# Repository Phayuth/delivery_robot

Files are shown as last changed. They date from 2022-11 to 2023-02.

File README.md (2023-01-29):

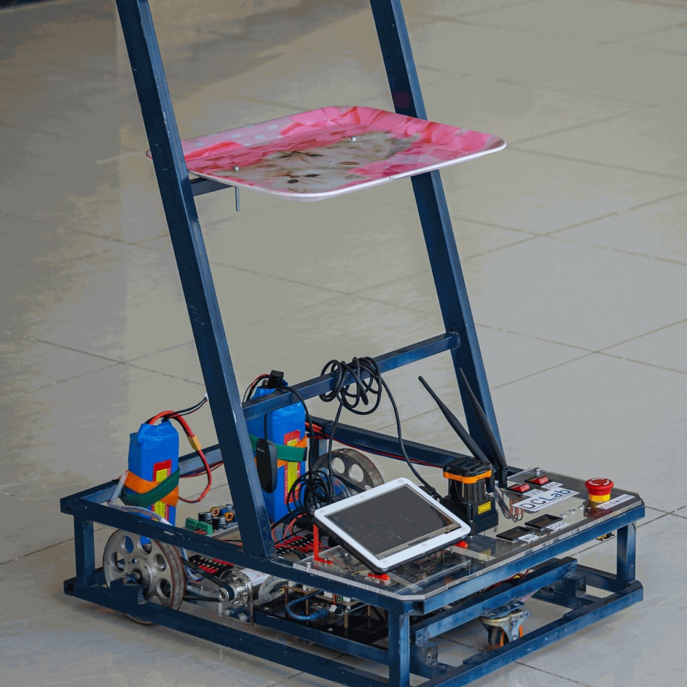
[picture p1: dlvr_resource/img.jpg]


# Delivery Mobile Robot
This Package is created for My Differential Drive Mobile Robot for Indoor Delivery. It is for ROS Melodic.[For Mom!]

### Reference [List](REFERENCES.md)
Some of the code is taken from some of other repo (all right belong to their respective author). There are detail of the package, read more in the references list link above.

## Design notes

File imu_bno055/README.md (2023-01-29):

# ROS driver for IMU Bosch BNO055 (I2C)
This is a ROS node for the BNO055 IMU that communicates via I2C and without any dependencies besides libi2c-dev. It does **not** require RTIMULib, RTIMULib2, RTIMULib3 or whatever the latest sequel is. It is specifically targeted at using a BNO055 with NVIDIA boards such as the TX1, TX2, and Xavier, or any other board that has native I2C.

The BNO055 supports I2C and UART communication. This driver supports I2C only. If you are looking for a UART driver, see [this driver](https://github.com/mdrwiega/bosch_imu_driver) by [mdrwiega](https://github.com/mdrwiega) instead.

## Parameters:

* **device** -- the path to the i2c device. Default is /dev/i2c-1. Use i2cdetect in the i2c-tools package to find out which bus your IMU is on.
* **address** -- the i2c address of the IMU. Default is 0x28.

## Outputs topics:
* **/data** (sensor\_msgs/Imu) -- fused IMU data
* **/raw** (sensor\_msgs/Imu) -- raw accelerometer data
* **/mag** (sensor\_msgs/MagneticField) -- raw magnetic field data
* **/temp** (sensor\_msgs/Temperature) -- temperature data
* **/status** (diagnostic\_msgs/DiagnosticStatus) -- a DiagnosticStatus object showing the current calibration, interrupt, system status of the IMU

## Service calls:
* **/reset** (std\_srvs/Trigger) -- resets the IMU
* **/calibrate** (std\_srvs/Trigger) -- not yet implemented

# Usage notes

## Raspberry Pi

The Raspberry Pi hardware I2C does not support clock stretching. You have two options:

* [Use software I2C](https://github.com/fivdi/i2c-bus/blob/master/doc/raspberry-pi-software-i2c.md) instead which supports clock stretching but will increase CPU usage slightly.
* [Slow down the I2C clock drastically](https://learn.adafruit.com/circuitpython-on-raspberrypi-linux/i2c-clock-stretching), since the Pi does not support clock stretching. I have not tested this method.

## NVIDIA Jetson platforms

You may need to add your user to the i2c group, e.g. `sudo usermod -aG i2c nvidia`. It should just work after that.

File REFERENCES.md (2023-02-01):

### Hardware
- 1 X Jetson Nano
- 1 X Arduino Due
- 1 X Custom Motor DiverIBT-2
- 1 X Custom Logic Level Converter
- 1 X IMU BNO055
- 2 X Gear DC Motor
- 1 X Lidar
- 1 X Camera
- 2 X Lipo Battery

### Install Prerequired Package
```
sudo apt-get install libgeographic-dev ros-melodic-libgeographic-info ros-melodic-libgeographic-dev
sudo apt-get install ros-melodic-openslam-gmapping ros-melodic-tf2-sensor-msgs
sudo apt-get install ros-melodic-laser-proc ros-melodic-urg-c
sudo apt-get install qt4-qmake qt4-dev-tools
sudo apt-get install ros-melodic-teleop-twist-keyboard
```
### Install Delivery Robot Package
-- To Do --

### Mobile Robot Parameter

| Params | Value |
|---|---|
| Width | ...m |
| Length | ...m |
| Height | ...m |
| Weight | ...kg |
| Base Length | 0.44 m |
| Wheel Radius | 0.07 m |
| Base to Caster Wheel | ...m |
| Ground Clearance | ...m |
| Motor Left a | 26.63 |
| Motor Left b | 17.26 |
| Motor Left c | 6.776 |
| Motor Left GR | 19.2x3.75 |
| Motor Left PPR | 28 |
| Motor Right a | 28.37 |
| Motor Right b | 19.15 |
| Motor Right c | 5.75 |
| Motor Right GR | 19.2x3.75 |
| Motor Right PPR | 28 |

### Support Repo
- [Hokuyo Lidar Package urg_node](https://github.com/ros-drivers/urg_node)
- [BNO055 Package](https://github.com/dheera/ros-imu-bno055)
- [Robot localization](https://github.com/cra-ros-pkg/robot_localization)
- [Gmapping](https://github.com/ros-perception/slam_gmapping)
- [Hector Slam](https://github.com/tu-darmstadt-ros-pkg/hector_slam)
- [ROS Navigation](http://wiki.ros.org/navigation)
- [ROS Serial](http://wiki.ros.org/rosserial)

### Other Repo
- [Grid Mapping](https://github.com/salihmarangoz/robot_laser_grid_mapping) - do a minimal laser grid mapping in python and ros
- [Laser Simulation from Image File](https://github.com/salihmarangoz/robot_laser_simulator) - create a simulation of laser scan from image file
- [Python for Robotic by AtsushiSakai](https://github.com/AtsushiSakai/PythonRobotics)

### Resoures and Issue
- [How to setup ros nav stack by automaticaddision](https://automaticaddison.com/how-to-set-up-the-ros-navigation-stack-on-a-robot/)
- [Arduino Due Board Installed on IDE](https://forum.arduino.cc/t/installing-arduino-sam-boards-on-arduino-ide-for-arm64/550398) - fix issue when installing arduino due board on nvidia jetson device
- [Why Odom frame and Map frame move away from each other](https://answers.ros.org/question/10302/the-tf-between-map-and-odom-is-not-static/#15185)
- [Install Hector SLAM](https://automaticaddison.com/how-to-build-an-indoor-map-using-ros-and-lidar-based-slam/)
- [Max range map](https://answers.ros.org/question/138591/gmapping-in-gazebo-with-hokuyo-problems-due-to-max-range-measurements/)
- [Pioneer 3pdx](https://www.generationrobots.com/media/Pioneer3DX-P3DX-RevA.pdf)

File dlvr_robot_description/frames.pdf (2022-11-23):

view_frames Result

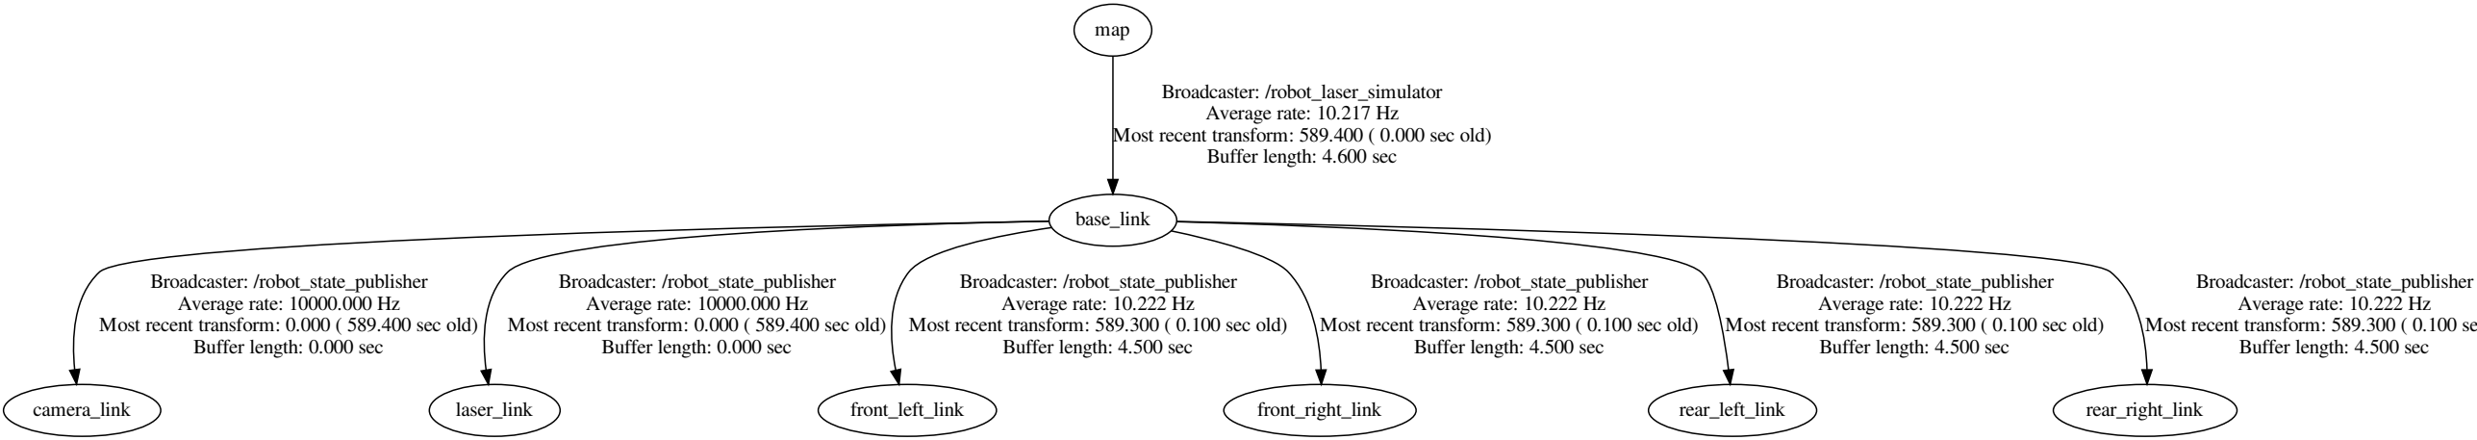
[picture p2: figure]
base_link; camera_link; Broadcaster: /robot_state_publisher Average rate: 10000.000 Hz; Buffer length: 0.000 sec; laser_link; front_left_link; Broadcaster: /robot_state_publisher Average rate: 10.222 Hz; Buffer length: 4.500 sec; front_right_link; rear_left_link; rear_right_link; map; Broadcaster: /robot_laser_simulator Average rate: 10.217 Hz; Buffer length: 4.600 sec

Most recent transform: 0.000 ( 589.400 sec old)

Most recent transform: 0.000 ( 589.400 sec old)

Most recent transform: 589.300 ( 0.100 sec old)

Most recent transform: 589.300 ( 0.100 sec old)

Most recent transform: 589.300 ( 0.100 sec old)

Most recent transform: 589.300 ( 0.100 sec old)

Most recent transform: 589.400 ( 0.000 sec old)

Recorded at time: 589.400

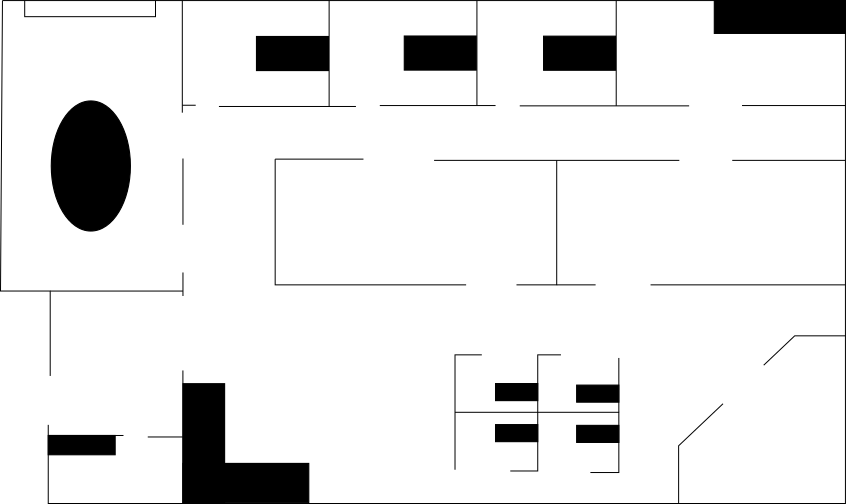
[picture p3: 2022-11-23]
dlvr_robot_laser_sim/launch/map1.png

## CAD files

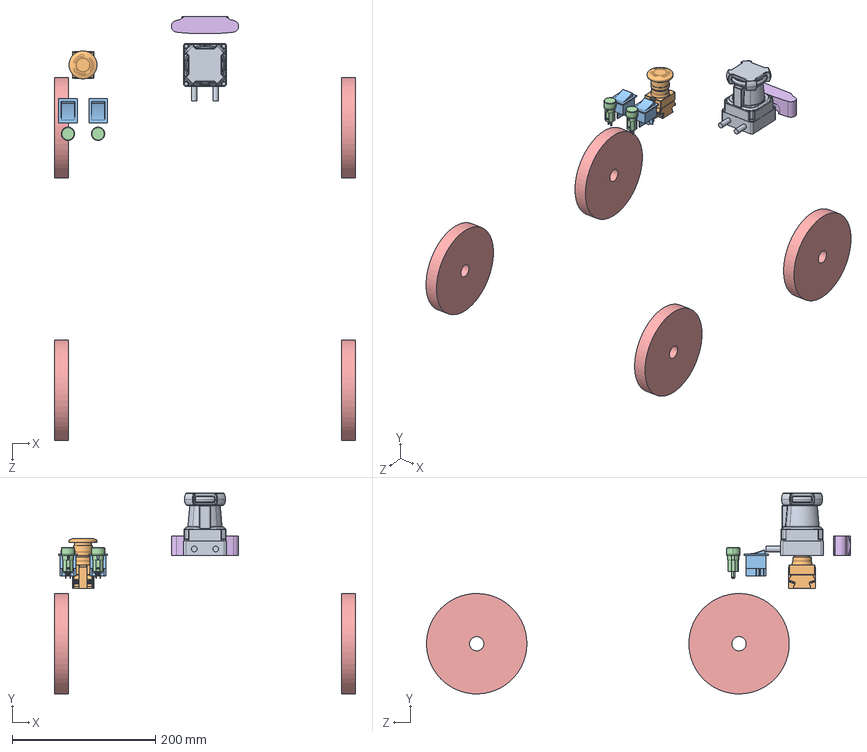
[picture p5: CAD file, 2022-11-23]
dlvr_resource/design/URDF_Export.SLDASM
420.0 x 280.0 x 591.0 mm
LIDAR_Hokuyo_UTM_30LX
E_Stop_Button
Battery_Switch x 2
LED_Indicator x 2
Wheel x 4
Logitech_C920

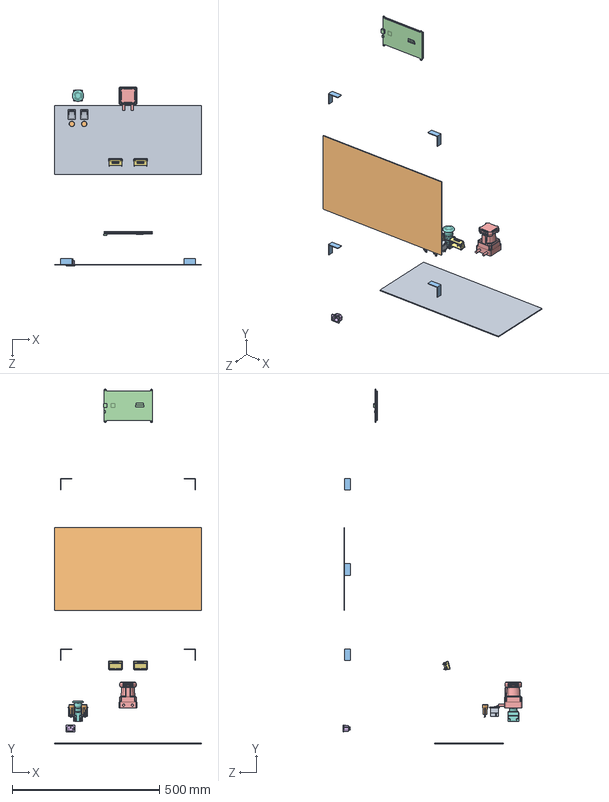
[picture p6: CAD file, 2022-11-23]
dlvr_resource/design/Assembly.SLDASM
500.0 x 1207.3 x 609.5 mm
Top_Back_Cover_2
Bottom_Battery_Support_1
Plate_Support x 6
LCD_Adafruit_HDMI_7inch
LIDAR_Hokuyo_UTM_30LX
AC_Power_Socket
Voltage_Display x 2
E_Stop_Button
Battery_Switch x 2
LED_Indicator x 2

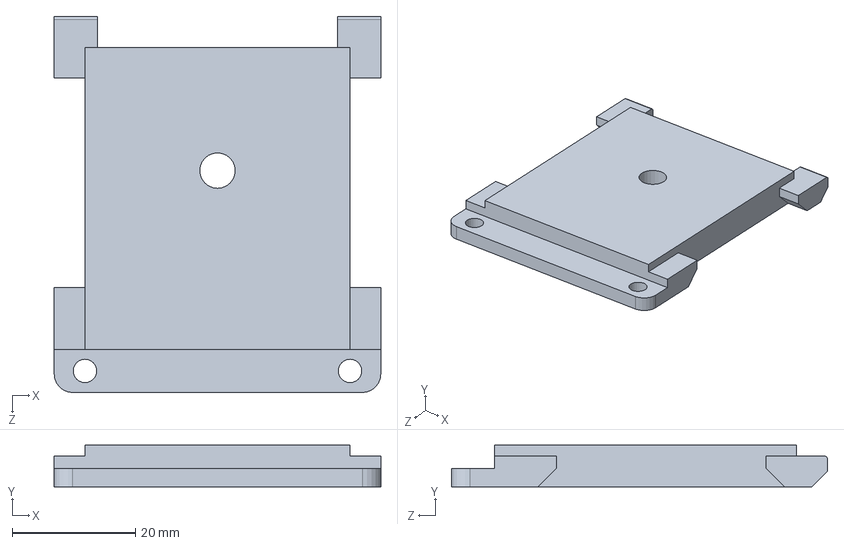
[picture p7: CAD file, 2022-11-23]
dlvr_resource/design/addon/delivery_camera_sup_b.SLDPRT
53.0 x 6.75 x 61.0 mm

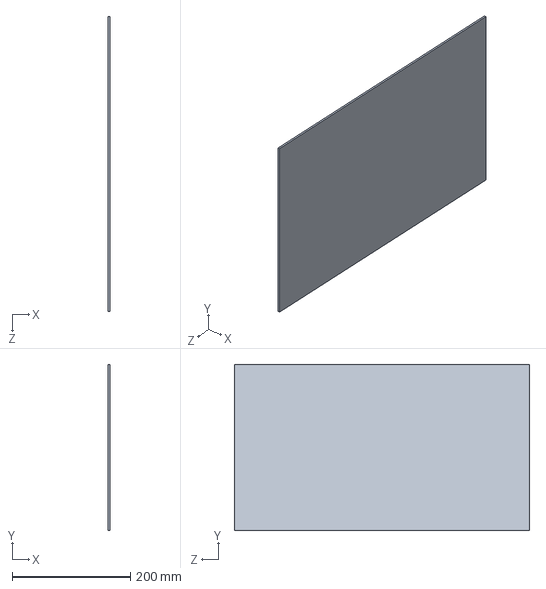
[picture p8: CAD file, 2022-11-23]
dlvr_resource/design/Part/Top_Back_Cover_2.SLDPRT
3.00 x 281.9 x 500.0 mm

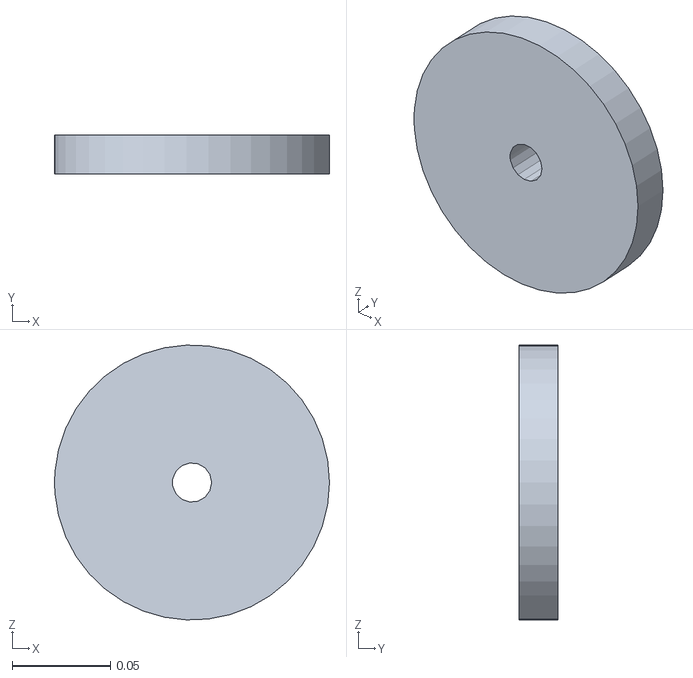
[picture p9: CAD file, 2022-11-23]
dlvr_robot_description/meshes/rear_left_link.STL
0.14 x 0.02 x 0.14

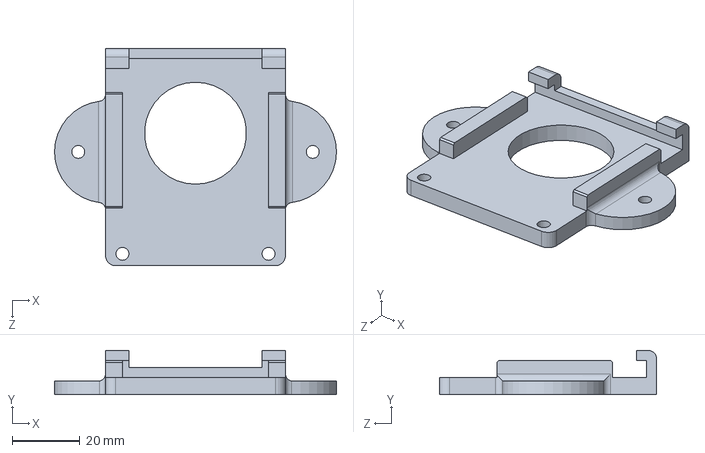
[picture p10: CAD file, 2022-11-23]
dlvr_resource/design/addon/delivery_camera_sup_a.SLDPRT
83.0 x 13.0 x 64.0 mm

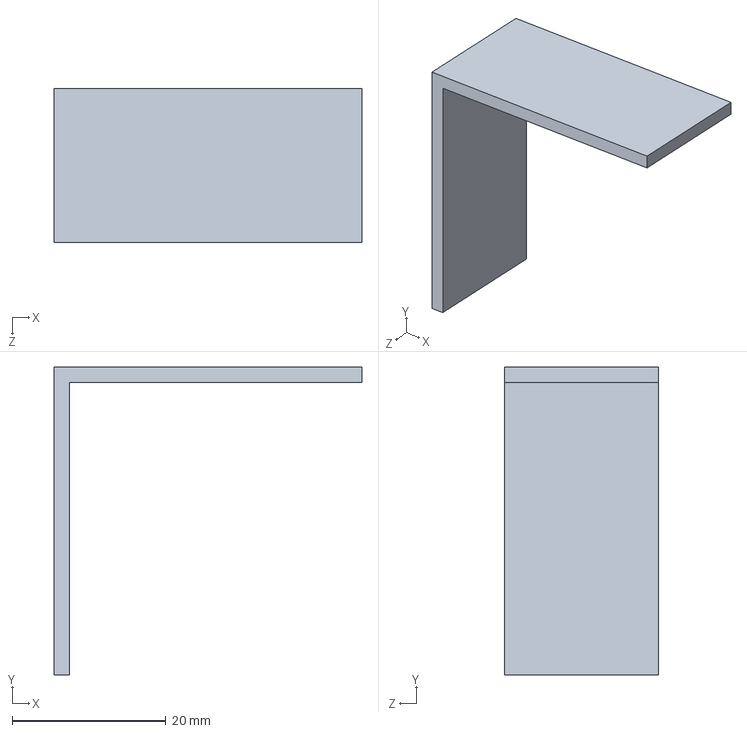
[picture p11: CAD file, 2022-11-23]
dlvr_resource/design/Part/Plate_Support.SLDPRT
40.0 x 40.0 x 20.0 mm

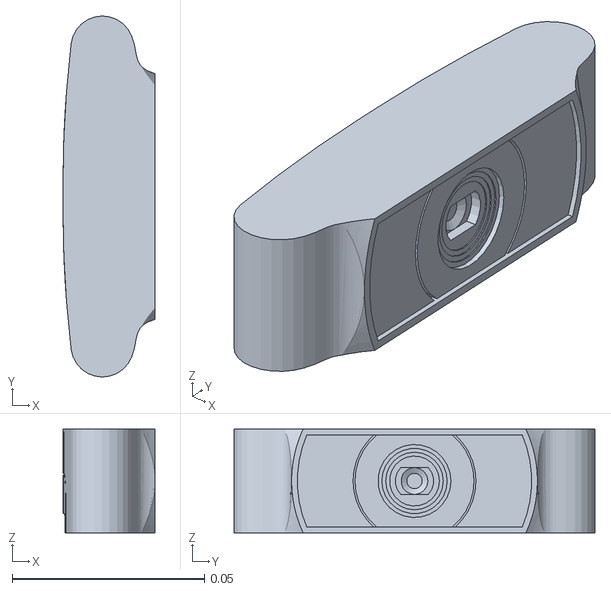
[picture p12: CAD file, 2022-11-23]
dlvr_robot_description/meshes/camera_link.STL
0.024 x 0.094 x 0.027

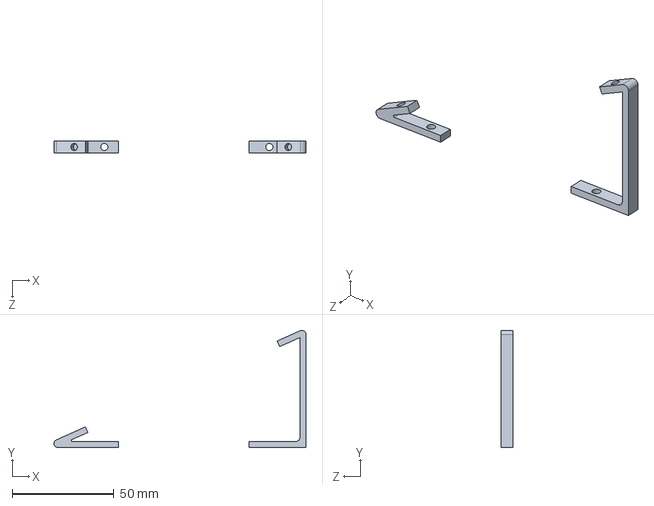
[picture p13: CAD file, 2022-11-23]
dlvr_resource/design/addon/delivery_ledscreen_sup.SLDPRT
123.6 x 57.5 x 6.00 mm

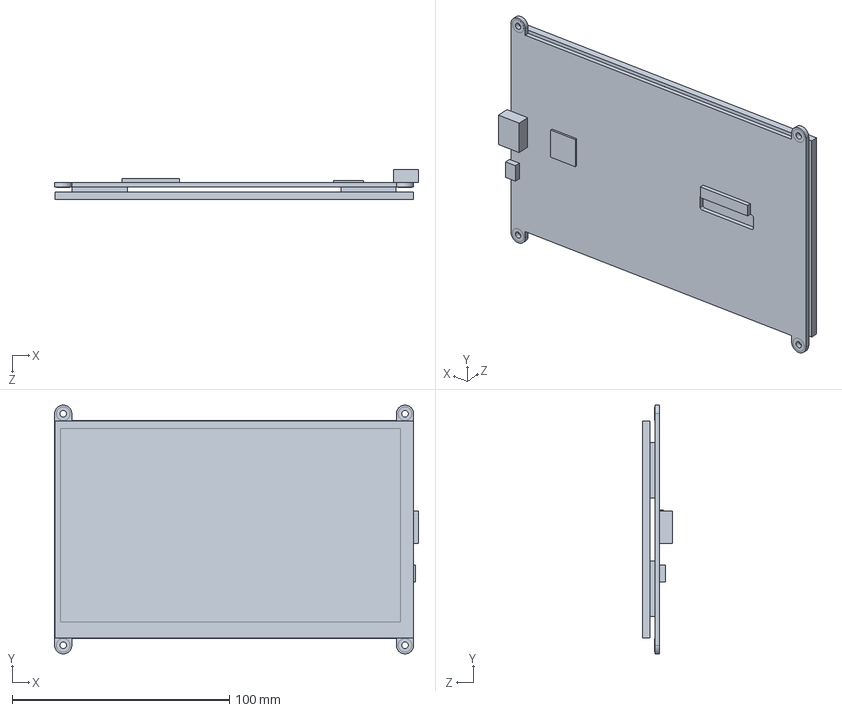
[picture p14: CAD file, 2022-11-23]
dlvr_resource/design/Part/LCD_Adafruit_HDMI_7inch.SLDPRT
167.4 x 114.5 x 14.0 mm

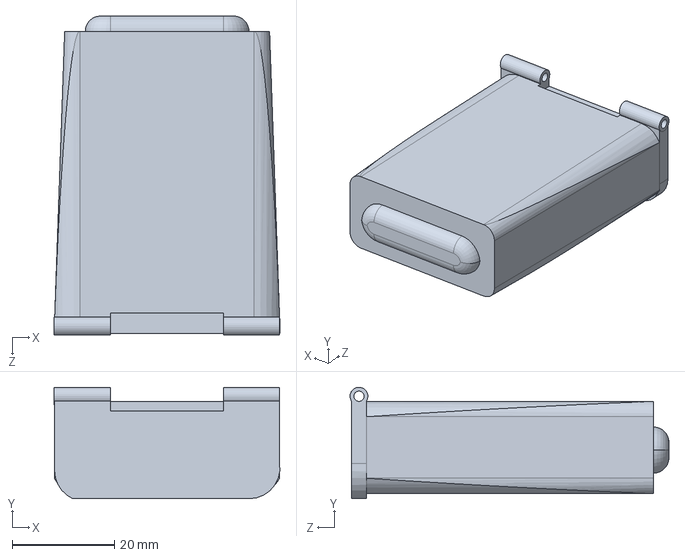
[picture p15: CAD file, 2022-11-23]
dlvr_resource/design/Part/Logitech_C920Arm.SLDPRT
44.0 x 21.8 x 62.2 mm

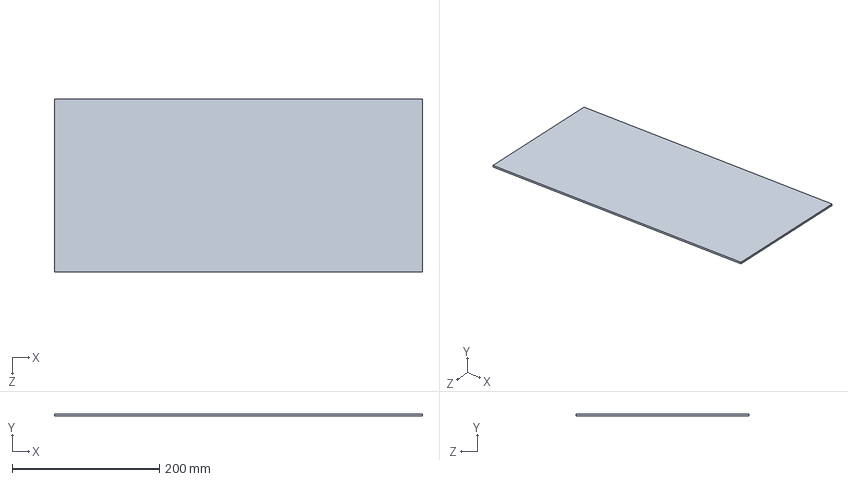
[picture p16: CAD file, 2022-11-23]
dlvr_resource/design/Part/Bottom_Battery_Support_1.SLDPRT
500.0 x 3.00 x 235.0 mm

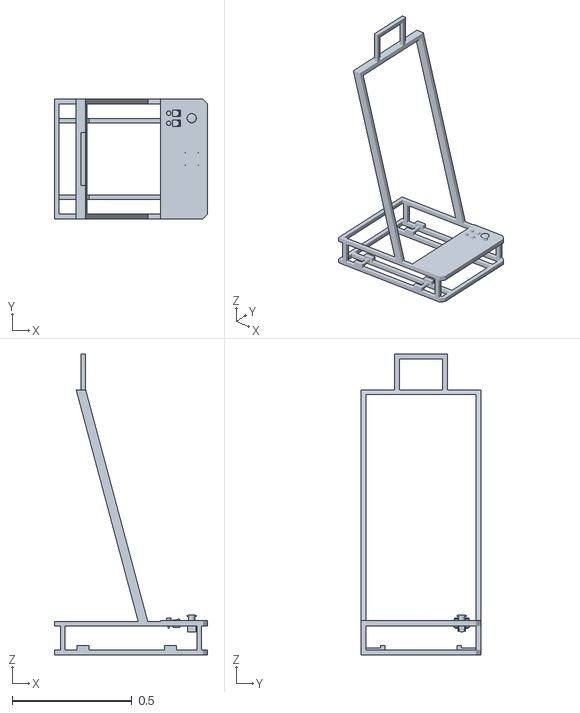
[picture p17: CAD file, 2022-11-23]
dlvr_robot_description/meshes/base_link.STL
0.64 x 0.5 x 1.26

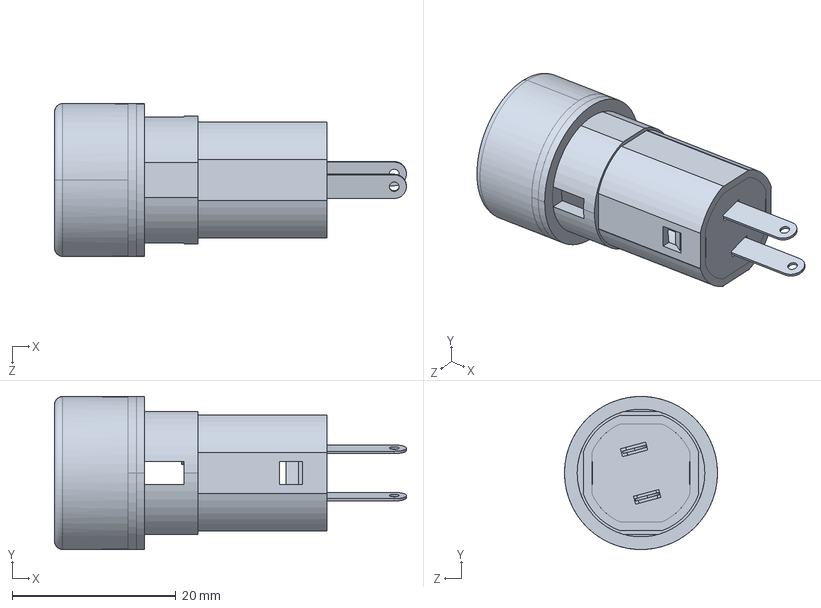
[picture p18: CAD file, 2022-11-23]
dlvr_resource/design/Part/LED_Indicator.SLDPRT
43.0 x 18.7 x 18.7 mm

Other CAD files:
dlvr_robot_description/meshes/rear_right_link.STL
dlvr_resource/design/Part/Voltage_Display.SLDPRT
dlvr_resource/design/Part/AC_Power_Socket.SLDPRT
dlvr_resource/design/Part/Battery_Switch.SLDPRT
dlvr_resource/design/Part/Bottom_Angle_Cover_1.SLDPRT
dlvr_resource/design/Part/Bottom_Angle_Cover_2.SLDPRT
dlvr_resource/design/Part/Bottom_Back_Cover.SLDPRT
dlvr_resource/design/Part/Bottom_Battery_Support_2.SLDPRT
dlvr_resource/design/Part/Bottom_Chamfer_Cover.SLDPRT
dlvr_resource/design/Part/Bottom_Front_Cover.SLDPRT
dlvr_resource/design/Part/Bottom_Side_Cover.SLDPRT
dlvr_resource/design/Part/E_Stop_Button.SLDPRT
dlvr_resource/design/Part/LCD_Support.SLDPRT
dlvr_resource/design/Part/LIDAR_Hokuyo_UTM_30LX.SLDPRT
dlvr_resource/design/Part/Logitech_C920.SLDPRT
dlvr_resource/design/Part/Plate.SLDPRT
dlvr_resource/design/Part/Structure.SLDPRT
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

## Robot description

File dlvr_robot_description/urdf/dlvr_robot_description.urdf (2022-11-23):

<?xml version="1.0" encoding="utf-8"?>
<!-- This URDF was automatically created by SolidWorks to URDF Exporter! Originally created by Stephen Brawner (brawner@gmail.com) 
     Commit Version: 1.6.0-4-g7f85cfe  Build Version: 1.6.7995.38578
     For more information, please see http://wiki.ros.org/sw_urdf_exporter -->
<robot name="dlvr_robot_description">
  <link name="base_link">
    <inertial>
      <origin xyz="0.168941119201691 0.00293699995115118 0.309676102260391" rpy="0 0 0" />
      <mass value="5.09472446197291" />
      <inertia ixx="1.01362205028955" ixy="-2.85959367357677E-05" ixz="0.14627068918848" iyy="0.977947360800656" iyz="1.41502121723081E-09" izz="0.374147086860137" />
    </inertial>
    <visual>
      <origin xyz="0 0 0" rpy="0 0 0" />
      <geometry>
        <mesh filename="package://dlvr_robot_description/meshes/base_link.STL" />
      </geometry>
      <material name="">
        <color rgba="0.792156862745098 0.819607843137255 0.933333333333333 1" />
      </material>
    </visual>
    <collision>
      <origin xyz="0 0 0" rpy="0 0 0" />
      <geometry>
        <mesh filename="package://dlvr_robot_description/meshes/base_link.STL" />
      </geometry>
    </collision>
  </link>
  <link name="rear_left_link">
    <inertial>
      <origin xyz="0 -2.77555756156289E-17 0" rpy="0 0 0" />
      <mass value="0.30159289474462" />
      <inertia ixx="0.000387044214922263" ixy="-3.80467942865772E-20" ixz="1.60866540289696E-35" iyy="0.000753982236861551" iyz="4.23174193314019E-37" izz="0.000387044214922263" />
    </inertial>
    <visual>
      <origin xyz="0 0 0" rpy="0 0 0" />
      <geometry>
        <mesh filename="package://dlvr_robot_description/meshes/rear_left_link.STL" />
      </geometry>
      <material name="">
        <color rgba="0.792156862745098 0.819607843137255 0.933333333333333 1" />
      </material>
    </visual>
    <collision>
      <origin xyz="0 0 0" rpy="0 0 0" />
      <geometry>
        <mesh filename="package://dlvr_robot_description/meshes/rear_left_link.STL" />
      </geometry>
    </collision>
  </link>
  <joint name="rear_left_joint" type="continuous">
    <origin xyz="0 0.2 -0.02" rpy="0 0 0" />
    <parent link="base_link" />
    <child link="rear_left_link" />
    <axis xyz="0 -1 0" />
    <limit effort="15" velocity="15" />
  </joint>
  <link name="rear_right_link">
    <inertial>
      <origin xyz="0 2.77555756156289E-17 0" rpy="0 0 0" />
      <mass value="0.30159289474462" />
      <inertia ixx="0.000387044214922263" ixy="1.33577016212533E-19" ixz="-5.32037942268733E-37" iyy="0.000753982236861551" iyz="-5.78563625795345E-37" izz="0.000387044214922263" />
    </inertial>
    <visual>
      <origin xyz="0 0 0" rpy="0 0 0" />
      <geometry>
        <mesh filename="package://dlvr_robot_description/meshes/rear_right_link.STL" />
      </geometry>
      <material name="">
        <color rgba="0.792156862745098 0.819607843137255 0.933333333333333 1" />
      </material>
    </visual>
    <collision>
      <origin xyz="0 0 0" rpy="0 0 0" />
      <geometry>
        <mesh filename="package://dlvr_robot_description/meshes/rear_right_link.STL" />
      </geometry>
    </collision>
  </link>
  <joint name="rear_right_joint" type="continuous">
    <origin xyz="0 -0.2 -0.02" rpy="0 0 0" />
    <parent link="base_link" />
    <child link="rear_right_link" />
    <axis xyz="0 1 0" />
    <limit effort="15" velocity="15" />
  </joint>
  <link name="front_left_link">
    <inertial>
      <origin xyz="0 0 0" rpy="0 0 0" />
      <mass value="0.30159289474462" />
      <inertia ixx="0.000387044214922263" ixy="-3.80467942865772E-20" ixz="1.60866540289696E-35" iyy="0.000753982236861551" iyz="4.23174193314021E-37" izz="0.000387044214922263" />
    </inertial>
    <visual>
      <origin xyz="0 0 0" rpy="0 0 0" />
      <geometry>
        <mesh filename="package://dlvr_robot_description/meshes/front_left_link.STL" />
      </geometry>
      <material name="">
        <color rgba="0.792156862745098 0.819607843137255 0.933333333333333 1" />
      </material>
    </visual>
    <collision>
      <origin xyz="0 0 0" rpy="0 0 0" />
      <geometry>
        <mesh filename="package://dlvr_robot_description/meshes/front_left_link.STL" />
      </geometry>
    </collision>
  </link>
  <joint name="front_left_joint" type="continuous">
    <origin xyz="0.36566 0.2 -0.02" rpy="0 0 0" />
    <parent link="base_link" />
    <child link="front_left_link" />
    <axis xyz="0 -1 0" />
    <limit effort="15" velocity="15" />
  </joint>
  <link name="front_right_link">
    <inertial>
      <origin xyz="0 0 0" rpy="0 0 0" />
      <mass value="0.30159289474462" />
      <inertia ixx="0.000387044214922263" ixy="-3.80467942865772E-20" ixz="1.60866540289696E-35" iyy="0.000753982236861551" iyz="3.94892633479361E-37" izz="0.000387044214922263" />
    </inertial>
    <visual>
      <origin xyz="0 0 0" rpy="0 0 0" />
      <geometry>
        <mesh filename="package://dlvr_robot_description/meshes/front_right_link.STL" />
      </geometry>
      <material name="">
        <color rgba="0.792156862745098 0.819607843137255 0.933333333333333 1" />
      </material>
    </visual>
    <collision>
      <origin xyz="0 0 0" rpy="0 0 0" />
      <geometry>
        <mesh filename="package://dlvr_robot_description/meshes/front_right_link.STL" />
      </geometry>
    </collision>
  </link>
  <joint name="front_right_joint" type="continuous">
    <origin xyz="0.36566 -0.2 -0.02" rpy="0 0 0" />
    <parent link="base_link" />
    <child link="front_right_link" />
    <axis xyz="0 1 0" />
    <limit effort="15" velocity="15" />
  </joint>
  <link name="laser_link">
    <inertial>
      <origin xyz="-0.0074290441733893 9.24567465299055E-10 -0.0169147007895237" rpy="0 0 0" />
      <mass value="0.229160261121681" />
      <inertia ixx="0.000208944155511789" ixy="1.30509407762921E-12" ixz="-1.13065684498391E-06" iyy="0.000213352225586718" iyz="-4.19240967763704E-12" izz="0.000112442330724859" />
    </inertial>
    <visual>
      <origin xyz="0 0 0" rpy="0 0 0" />
      <geometry>
        <mesh filename="package://dlvr_robot_description/meshes/laser_link.STL" />
      </geometry>
      <material name="">
        <color rgba="0 0 0 1" />
      </material>
    </visual>
    <collision>
      <origin xyz="0 0 0" rpy="0 0 0" />
      <geometry>
        <mesh filename="package://dlvr_robot_description/meshes/laser_link.STL" />
      </geometry>
    </collision>
  </link>
  <joint name="laser_joint" type="fixed">
    <origin xyz="0.46029 0 0.15775" rpy="0 0 0" />
    <parent link="base_link" />
    <child link="laser_link" />
    <axis xyz="0 0 0" />
  </joint>
  <link name="camera_link">
    <inertial>
      <origin xyz="-0.00671854201515454 -1.06281777678558E-07 0.000966339550162953" rpy="0 0 0" />
      <mass value="0.0470288707068897" />
      <inertia ixx="3.37748134686876E-05" ixy="3.09228399625322E-11" ixz="8.44203479212471E-08" iyy="4.39178954043211E-06" iyz="-2.65874618424396E-12" izz="3.29793928553019E-05" />
    </inertial>
    <visual>
      <origin xyz="0 0 0" rpy="0 0 0" />
      <geometry>
        <mesh filename="package://dlvr_robot_description/meshes/camera_link.STL" />
      </geometry>
      <material name="">
        <color rgba="0.792156862745098 0.819607843137255 0.933333333333333 1" />
      </material>
    </visual>
    <collision>
      <origin xyz="0 0 0" rpy="0 0 0" />
      <geometry>
        <mesh filename="package://dlvr_robot_description/meshes/camera_link.STL" />
      </geometry>
    </collision>
  </link>
  <joint name="camera_joint" type="fixed">
    <origin xyz="0.51525 0 0.1165" rpy="0 0 0" />
    <parent link="base_link" />
    <child link="camera_link" />
    <axis xyz="0 0 0" />
  </joint>
</robot>

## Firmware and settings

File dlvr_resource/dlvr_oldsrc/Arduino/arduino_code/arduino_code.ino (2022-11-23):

// Include library
#define USE_USBCON // For Arduino Due rosserial in every board and computer
#include <ros.h>
#include <std_msgs/Int32.h>
#include <sensor_msgs/Imu.h>
#include <geometry_msgs/Twist.h>
#include <Wire.h>
#include <Adafruit_Sensor.h>
#include <Adafruit_BNO055.h>
#include <utility/imumaths.h>
#include <ros/time.h>
#include <tf/tf.h>
#include <tf/transform_broadcaster.h>
#include <geometry_msgs/Quaternion.h>

// Handles startup and shutdown of ROS
ros::NodeHandle nh;

// Init IMU object
Adafruit_BNO055 myIMU = Adafruit_BNO055(55, 0x28);

// Encoder and Motor Left
#define left_motor_Rpwm_pin 5
#define left_motor_Lpwm_pin 4
int counter_left = 0;
uint8_t Pin_left_A = 10;
uint8_t Pin_left_B = 11;
uint8_t Interrupt_left_A = 10;
uint8_t Interrupt_left_B = 11;

// Encoder and Motor Right
#define right_motor_Rpwm_pin 7
#define right_motor_Lpwm_pin 6
int counter_right = 0;
uint8_t Pin_right_A = 8;
uint8_t Pin_right_B = 9;
uint8_t Interrupt_right_A = 8;
uint8_t Interrupt_right_B = 9;

// preassign variable
double left_pwm; // pwm for left wheel
double right_pwm; // pwm for right wheel

// mobile robot parameter
double V;      // linear velocity
double omega;  // angular velocity
double L = 0.44;  // robot base length in m
double r = 0.07;  // robot wheel radius in m
double left_speed;  // omega left wheel rad/s
double right_speed; // omega right wheel rad/s

// Minumum and maximum values for 16-bit integers
//const int encoder_minimum = -32768;
//const int encoder_maximum = 32767;

// callback function for subcribe to twist msg
void twist_cb(const geometry_msgs::Twist& msg)
{
  // get linear and angular velocity from twist
  V = msg.linear.x;
  omega = msg.angular.z;

  // convert V and omega to each wheel speed
  left_speed = (2 * V - L * omega) / (2 * r);
  right_speed = (2 * V + L * omega) / (2 * r);

  // convert each wheel speed to pwm value, y=Ax+b, A=0.22,b=0.1
  left_pwm = 1 * left_speed + 0;
  right_pwm = 1 * right_speed + 0;

  // limit pwm
  if (left_pwm < -250) {
    left_pwm = -250;
  }
  if (left_pwm > 250) {
    left_pwm = 250;
  }
  if (right_pwm < -250) {
    right_pwm = -250;
  }
  if (right_pwm > 250) {
    right_pwm = 250;
  }

  // write pwm to pin
  if ( left_pwm < 0 && right_pwm < 0) {
    // left reverse , right reverse
    analogWrite(left_motor_Rpwm_pin, 0);
    analogWrite(left_motor_Lpwm_pin, left_pwm * -1);
    analogWrite(right_motor_Rpwm_pin, 0);
    analogWrite(right_motor_Lpwm_pin, right_pwm * -1);
  }
  else if ( left_pwm > 0 && right_pwm > 0) {
    // left forward , right forward
    analogWrite(left_motor_Rpwm_pin, left_pwm);
    analogWrite(left_motor_Lpwm_pin, 0);
    analogWrite(right_motor_Rpwm_pin, right_pwm);
    analogWrite(right_motor_Lpwm_pin, 0);
  }
  else if ( left_pwm < 0 && right_pwm > 0) {
    // left reverse , right forward
    analogWrite(left_motor_Rpwm_pin, 0);
    analogWrite(left_motor_Lpwm_pin, left_pwm * -1);
    analogWrite(right_motor_Rpwm_pin, right_pwm);
    analogWrite(right_motor_Lpwm_pin, 0);
  }
  else if ( left_pwm > 0 && right_pwm < 0) {
    // left forward , right reverse
    analogWrite(left_motor_Rpwm_pin, left_pwm);
    analogWrite(left_motor_Lpwm_pin, 0);
    analogWrite(right_motor_Rpwm_pin, 0);
    analogWrite(right_motor_Lpwm_pin, right_pwm * -1);
  }
  else {
    // neutral
    analogWrite(left_motor_Rpwm_pin, 0);
    analogWrite(left_motor_Lpwm_pin, 0);
    analogWrite(right_motor_Rpwm_pin, 0);
    analogWrite(right_motor_Lpwm_pin, 0);
  }
}

// Init Encoder Pub
std_msgs::Int32 right_wheel_tick_count;
ros::Publisher rightPub("right_ticks", &right_wheel_tick_count);

std_msgs::Int32 left_wheel_tick_count;
ros::Publisher leftPub("left_ticks", &left_wheel_tick_count);

// Init Imu Pub
sensor_msgs::Imu imu_data;
ros::Publisher imupub("imu", &imu_data);
geometry_msgs::Quaternion q;

// Init Twist Sub
ros::Subscriber<geometry_msgs::Twist> twt_sub("/cmd_vel", &twist_cb);

// 100ms interval for measurements
const int interval = 100;
long previousMillis = 0;
long currentMillis = 0;

void setup() {
  // Motor
  pinMode(left_motor_Rpwm_pin, OUTPUT);
  pinMode(left_motor_Lpwm_pin, OUTPUT);
  pinMode(right_motor_Rpwm_pin, OUTPUT);
  pinMode(right_motor_Lpwm_pin, OUTPUT);

  // Interupt encoder
  pinMode(Pin_left_A, INPUT_PULLUP);
  pinMode(Pin_left_B, INPUT_PULLUP);
  pinMode(Pin_right_A, INPUT_PULLUP);
  pinMode(Pin_right_B, INPUT_PULLUP);
  attachInterrupt(Interrupt_left_A, ai10, CHANGE);
  attachInterrupt(Interrupt_left_B, ai11, CHANGE);
  attachInterrupt(Interrupt_right_A, ai8, CHANGE);
  attachInterrupt(Interrupt_right_B, ai9, CHANGE);

  // IMU
  myIMU.begin();
  delay(1000);
  myIMU.setExtCrystalUse(true);

  // ROS Setup
  //nh.getHardware()->setBaud(115200);
  nh.initNode();
  nh.subscribe(twt_sub); // start subscribe to sub
  nh.advertise(rightPub);
  nh.advertise(leftPub);
  nh.advertise(imupub);
}

void loop() {

  // Record the time
  currentMillis = millis();

  // If 100ms have passed, print the number of ticks
  if (currentMillis - previousMillis > interval) {

    previousMillis = currentMillis;

    uint8_t system, gyro, accel, mg = 0;
    myIMU.getCalibration(&system, &gyro, &accel, &mg);
    imu::Vector<3> acc = myIMU.getVector(Adafruit_BNO055::VECTOR_ACCELEROMETER);
    imu::Vector<3> gyr = myIMU.getVector(Adafruit_BNO055::VECTOR_GYROSCOPE);
    imu::Vector<3> rpy = myIMU.getVector(Adafruit_BNO055::VECTOR_EULER);

    //populate data to msg
    //imu_data.header.seq = 0;
    //imu_data.header.stamp = 0;
    imu_data.header.frame_id = "imu_link";

    q = tf::createQuaternionFromYaw(rpy.z());
    
    imu_data.orientation.x = q.x;
    imu_data.orientation.y = q.y;
    imu_data.orientation.z = q.z;
    imu_data.orientation.w = q.w;

    imu_data.angular_velocity.x = gyr.x();
    imu_data.angular_velocity.y = gyr.y();
    imu_data.angular_velocity.z = gyr.z();

    imu_data.linear_acceleration.x = acc.x();
    imu_data.linear_acceleration.y = acc.y();
    imu_data.linear_acceleration.z = acc.z();

    //rightPub.publish( &right_wheel_tick_count );
    //leftPub.publish( &left_wheel_tick_count );
    imupub.publish( &imu_data );
  }
  rightPub.publish( &right_wheel_tick_count );
  leftPub.publish( &left_wheel_tick_count );
  nh.spinOnce(); // "spinonce" have to be outside of "if" to avoid msg not publish
}

void ai10() {
  if (digitalRead(Pin_left_A) == HIGH) {
    if (digitalRead(Pin_left_B) == LOW) {
      counter_left--;
    }
    else {
      counter_left++;
    }
  }
  else {
    if (digitalRead(Pin_left_B) == LOW) {
      counter_left++;
    }
    else {
      counter_left--;
    }
  }
  left_wheel_tick_count.data = counter_left;
}

void ai11() {
  if (digitalRead(Pin_left_B) == HIGH) {
    if (digitalRead(Pin_left_A) == LOW) {
      counter_left++;
    }
    else {
      counter_left--;
    }
  }
  else {
    if (digitalRead(Pin_left_A) == LOW) {
      counter_left--;
    }
    else {
      counter_left++;
    }
  }
  left_wheel_tick_count.data = counter_left;
}


void ai8() {
  if (digitalRead(Pin_right_A) == HIGH) {
    if (digitalRead(Pin_right_B) == LOW) {
      counter_right++;
    }
    else {
      counter_right--;
    }
  }
  else {
    if (digitalRead(Pin_right_B) == LOW) {
      counter_right--;
    }
    else {
      counter_right++;
    }
  }
  right_wheel_tick_count.data = counter_right;
}

void ai9() {
  if (digitalRead(Pin_right_B) == HIGH) {
    if (digitalRead(Pin_right_A) == LOW) {
      counter_right--;
    }
    else {
      counter_right++;
    }
  }
  else {
    if (digitalRead(Pin_right_A) == LOW) {
      counter_right++;
    }
    else {
      counter_right--;
    }
  }
  right_wheel_tick_count.data = counter_right;
}

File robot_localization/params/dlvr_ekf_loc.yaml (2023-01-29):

# The frequency, in Hz, at which the filter will output a position estimate. Note that the filter will not begin
# computation until it receives at least one message from one of the inputs. It will then run continuously at the
# frequency specified here, regardless of whether it receives more measurements. Defaults to 30 if unspecified.
frequency: 30

silent_tf_failure: false
# The period, in seconds, after which we consider a sensor to have timed out. In this event, we carry out a predict
# cycle on the EKF without correcting it. This parameter can be thought of as the minimum frequency with which the
# filter will generate new output. Defaults to 1 / frequency if not specified.
sensor_timeout: 0.1

# ekf_localization_node and ukf_localization_node both use a 3D omnidirectional motion model. If this parameter is
# set to true, no 3D information will be used in your state estimate. Use this if you are operating in a planar
# environment and want to ignore the effect of small variations in the ground plane that might otherwise be detected
# by, for example, an IMU. Defaults to false if unspecified.
two_d_mode: true

# Use this parameter to provide an offset to the transform generated by ekf_localization_node. This can be used for
# future dating the transform, which is required for interaction with some other packages. Defaults to 0.0 if
# unspecified.
transform_time_offset: 0.0

# Use this parameter to provide specify how long the tf listener should wait for a transform to become available. 
# Defaults to 0.0 if unspecified.
transform_timeout: 0.0

# If you're having trouble, try setting this to true, and then echo the /diagnostics_agg topic to see if the node is
# unhappy with any settings or data.
print_diagnostics: true

# Debug settings. Not for the faint of heart. Outputs a ludicrous amount of information to the file specified by
# debug_out_file. I hope you like matrices! Please note that setting this to true will have strongly deleterious
# effects on the performance of the node. Defaults to false if unspecified.
debug: false

# Defaults to "robot_localization_debug.txt" if unspecified. Please specify the full path.
debug_out_file: ./robot_loc_debug_file.txt

# Whether to broadcast the transformation over the /tf topic. Defaults to true if unspecified.
publish_tf: true

# Whether to publish the acceleration state. Defaults to false if unspecified.
publish_acceleration: false

# REP-105 (http://www.ros.org/reps/rep-0105.html) specifies four principal coordinate frames: base_link, odom, map, and
# earth. base_link is the coordinate frame that is affixed to the robot. Both odom and map are world-fixed frames.
# The robot's position in the odom frame will drift over time, but is accurate in the short term and should be
# continuous. The odom frame is therefore the best frame for executing local motion plans. The map frame, like the odom
# frame, is a world-fixed coordinate frame, and while it contains the most globally accurate position estimate for your
# robot, it is subject to discrete jumps, e.g., due to the fusion of GPS data or a correction from a map-based
# localization node. The earth frame is used to relate multiple map frames by giving them a common reference frame.
# ekf_localization_node and ukf_localization_node are not concerned with the earth frame.
# Here is how to use the following settings:
# 1. Set the map_frame, odom_frame, and base_link frames to the appropriate frame names for your system.
#     1a. If your system does not have a map_frame, just remove it, and make sure "world_frame" is set to the value of
#         odom_frame.
# 2. If you are fusing continuous position data such as wheel encoder odometry, visual odometry, or IMU data, set
#   "world_frame" to your odom_frame value. This is the default behavior for robot_localization's state estimation nodes.
# 3. If you are fusing global absolute position data that is subject to discrete jumps (e.g., GPS or position updates
# from landmark observations) then:
#     3a. Set your "world_frame" to your map_frame value
#     3b. MAKE SURE something else is generating the odom->base_link transform. Note that this can even be another state
#         estimation node from robot_localization! However, that instance should *not* fuse the global data.
# map_frame: map              # Defaults to "map" if unspecified
odom_frame: odom            # Defaults to "odom" if unspecified
base_link_frame: base_link  # Defaults to "base_link" if unspecified
world_frame: odom           # Defaults to the value of odom_frame if unspecified

# From Wheel Encoder
odom0: dlvr/sensor_wheel_enc_odom
odom0_config: [true,  true,  false,
               false, false, false,
               false, false, false,
               false, false, true,
               false, false, false]

odom0_queue_size: 2
odom0_nodelay: false
odom0_differential: false
odom0_relative: false
odom0_pose_rejection_threshold: 5
odom0_twist_rejection_threshold: 1
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

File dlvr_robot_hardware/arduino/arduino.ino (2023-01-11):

// Include library
#define USE_USBCON
#include <ros.h>
#include <dlvr_robot_msg/motor_stat.h>
#include <std_msgs/Float32.h>
#include <ros/time.h>

// Time interval for handling control loop
unsigned long time_old, time_new;
float Ts;

// Time interval for handling publish
const int motor_interval = 30;
unsigned long motor_previousMillis = 0;
unsigned long motor_currentMillis = 0;

float pi = 3.141592653;

// Left Motor and Encoder
#define L_pwm_pin 5
#define L_dir_pin 4
int L_counter = 0;
uint8_t L_enc_A = 10;
uint8_t L_enc_B = 11;

// Left Motor Parameters
float L_a = 26.63;
float L_b = 17.26;
float L_PPR = 28;
float L_GR = 19.2 * 3.75;
float L_theta_p = 0;
float L_theta_c = 0;
float L_omega_d = 0;
float L_omega_d_p = 0;
float L_omega_c = 0;

// Left Motor PID Parameters
float L_kp = (2 * 1 * 2 * pi * 6 - L_a) / L_b;
float L_ki = (2 * pi * 6 * 2 * pi * 6) / L_b;
float L_cumError = 0;
float L_error = 0;
float L_u = 0;
int L_pwm;

// -----------------------------------------------------------------------------

// Right Motor and Encoder
#define R_pwm_pin 6
#define R_dir_pin 7
int R_counter = 0;
uint8_t R_enc_A = 8;
uint8_t R_enc_B = 9;

// Right Motor Parameters
float R_a = 28.37;
float R_b = 19.15;
float R_PPR = 28;
float R_GR = 19.2 * 3.75;
float R_theta_p = 0;
float R_theta_c = 0;
float R_omega_d = 0;
float R_omega_d_p = 0;
float R_omega_c = 0;

// Right Motor PID Parameters
float R_kp = (2 * 1 * 2 * pi * 6 - R_a) / R_b;
float R_ki = (2 * pi * 6 * 2 * pi * 6) / R_b;
float R_cumError = 0;
float R_error = 0;
float R_u = 0;
int R_pwm;

// ROS -------------------------------------------------------------------------
ros::NodeHandle nh;
void left_cmd_pwm_cb(const std_msgs::Float32& msg); // function prototype
void right_cmd_pwm_cb(const std_msgs::Float32& msg); // function prototype

// Publish Motor Stat
dlvr_robot_msg::motor_stat pub_motor_stat;
ros::Publisher motorPub("/dlvr/motor_stat", &pub_motor_stat);

// Subscribe Left/Right wheel velocity
ros::Subscriber<std_msgs::Float32> left_sub("/dlvr/left_motor_desired", &left_cmd_pwm_cb);
ros::Subscriber<std_msgs::Float32> right_sub("/dlvr/right_motor_desired", &right_cmd_pwm_cb);
// ROS -------------------------------------------------------------------------

void setup() {
  // Motor
  pinMode(L_pwm_pin, OUTPUT);
  pinMode(L_dir_pin, OUTPUT);
  pinMode(R_pwm_pin, OUTPUT);
  pinMode(R_dir_pin, OUTPUT);

  // Interupt encoder
  pinMode(L_enc_A, INPUT_PULLUP);
  pinMode(L_enc_B, INPUT_PULLUP);
  pinMode(R_enc_A, INPUT_PULLUP);
  pinMode(R_enc_B, INPUT_PULLUP);
  attachInterrupt(L_enc_A, ai10, CHANGE);
  attachInterrupt(L_enc_B, ai11, CHANGE);
  attachInterrupt(R_enc_A, ai8, CHANGE);
  attachInterrupt(R_enc_B, ai9, CHANGE);

  // Time Record
  time_old = millis();
  time_new = millis();

  // ROS Setup
  nh.getHardware()->setBaud(115200);
  nh.initNode();
  nh.subscribe(left_sub);
  nh.subscribe(right_sub);
  nh.advertise(motorPub);
}

void loop() {
  // Find out how time has passed
  delay(1);
  time_new = millis(); // handle control loop
  motor_currentMillis = millis(); // handle publisher loop

  Ts = (time_new - time_old) * 0.001; // convert from milli second (ms) to second(s)

  // Find current theta and find omega
  R_theta_c = tick_2_theta(R_counter, R_PPR, R_GR);
  R_omega_c = (R_theta_c - R_theta_p) / Ts;
  L_theta_c = tick_2_theta(L_counter, L_PPR, L_GR);
  L_omega_c = (L_theta_c - L_theta_p) / Ts;

  // Calculate different error
  R_error = R_omega_d - R_omega_c;
  L_error = L_omega_d - L_omega_c;

  // Calculate input voltage
  R_u = (R_kp * R_error) + (R_ki * (R_cumError + R_error * Ts)) + ((R_a / R_b) * R_omega_d) + ((1 / R_b) * ((R_omega_d - R_omega_d_p) / Ts));
  L_u = (L_kp * L_error) + (L_ki * (L_cumError + L_error * Ts)) + ((L_a / L_b) * L_omega_d) + ((1 / L_b) * ((L_omega_d - L_omega_d_p) / Ts));

  // Write control value to motor
  R_pwm = pwm_cal(R_u, 23.5);
  L_pwm = pwm_cal(L_u, 23.5);
  R_write_pwm(R_pwm);
  L_write_pwm(L_pwm);

  //Publish stat
  if (motor_currentMillis - motor_previousMillis > motor_interval)
  {
    motor_previousMillis = motor_currentMillis;

    pub_motor_stat.header.stamp = nh.now();
    pub_motor_stat.header.frame_id = "motor";
    pub_motor_stat.speed_left = L_omega_c;
    pub_motor_stat.encoder_left = L_counter;
    pub_motor_stat.speed_right = R_omega_c;
    pub_motor_stat.encoder_right = R_counter;

    motorPub.publish( &pub_motor_stat );
  }

  // Update for next time step
  time_old = time_new;

  L_theta_p = L_theta_c;
  R_theta_p = R_theta_c;

  L_cumError += L_error * Ts;
  R_cumError += R_error * Ts;

  L_omega_d_p = L_omega_d;
  R_omega_d_p = R_omega_d;

  nh.spinOnce();
}

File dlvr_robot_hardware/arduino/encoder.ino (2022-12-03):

void ai10() {
  if (digitalRead(L_enc_A) == HIGH) {
    if (digitalRead(L_enc_B) == LOW) {
      L_counter--;
    }
    else {
      L_counter++;
    }
  }
  else {
    if (digitalRead(L_enc_B) == LOW) {
      L_counter++;
    }
    else {
      L_counter--;
    }
  }
}

void ai11() {
  if (digitalRead(L_enc_B) == HIGH) {
    if (digitalRead(L_enc_A) == LOW) {
      L_counter++;
    }
    else {
      L_counter--;
    }
  }
  else {
    if (digitalRead(L_enc_A) == LOW) {
      L_counter--;
    }
    else {
      L_counter++;
    }
  }
}


void ai8() {
  if (digitalRead(R_enc_A) == HIGH) {
    if (digitalRead(R_enc_B) == LOW) {
      R_counter++;
    }
    else {
      R_counter--;
    }
  }
  else {
    if (digitalRead(R_enc_B) == LOW) {
      R_counter--;
    }
    else {
      R_counter++;
    }
  }
}

void ai9() {
  if (digitalRead(R_enc_B) == HIGH) {
    if (digitalRead(R_enc_A) == LOW) {
      R_counter--;
    }
    else {
      R_counter++;
    }
  }
  else {
    if (digitalRead(R_enc_A) == LOW) {
      R_counter++;
    }
    else {
      R_counter--;
    }
  }
}

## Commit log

2022-12-03 update with hardware
    [AC_Power_Socket.SLDPRT, Assembly.SLDASM, Battery_Switch.SLDPRT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]
2022-12-22 update arduino
2023-01-29 large update
    [AMCL.cfg, BaseLocalPlanner.cfg, DWAPlanner.cfg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]
